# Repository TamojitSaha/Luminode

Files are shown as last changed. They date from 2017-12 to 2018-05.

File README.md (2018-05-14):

<h1 align="center"> LumiNode </h1> <br>

## Table of Contents
- [Introduction](#introduction)
- [Bill of Materials](#bill-of-materials)
- [Features](#features)
- [Contributors](#Contributors)
- [License](#license)
- [Acknowledgments](#acknowledgments)

## Introduction





A wireless multipurpose IoT (Internet of Things) compatible smart light system that can reproduce colour from any image in RGB colour space with intensity adjustment capability.
It is open-source and built for Arduino ecosystem making it suitable for hobbysist and beginners.
<p align="center">
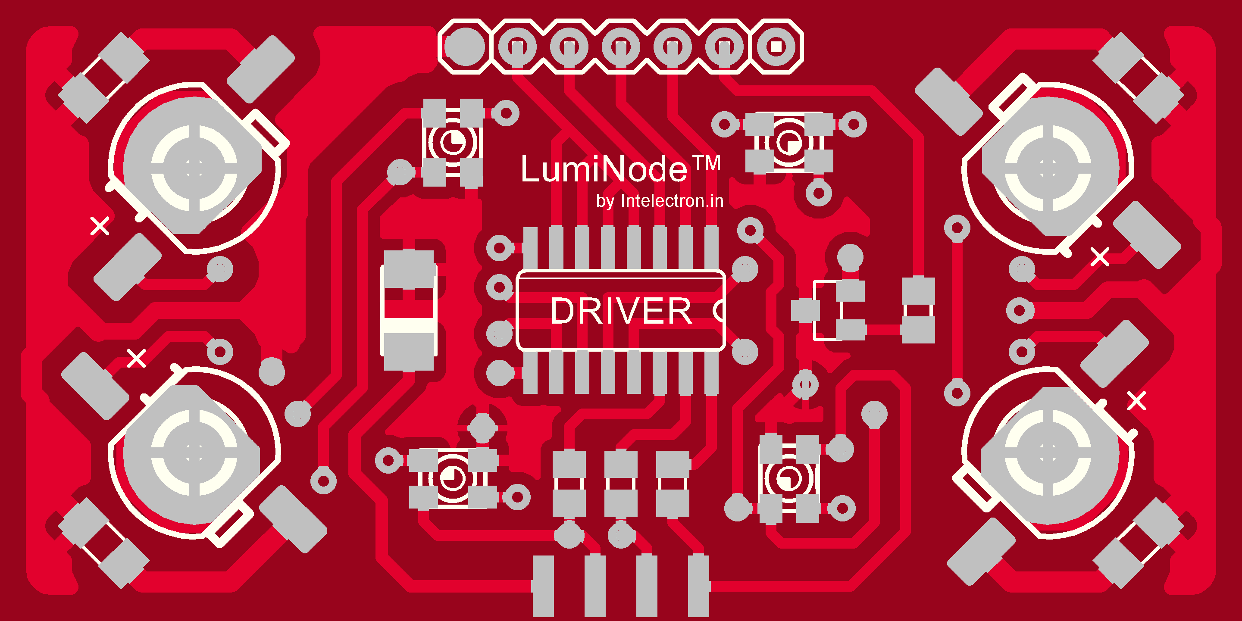
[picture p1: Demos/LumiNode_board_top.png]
  &nbsp 
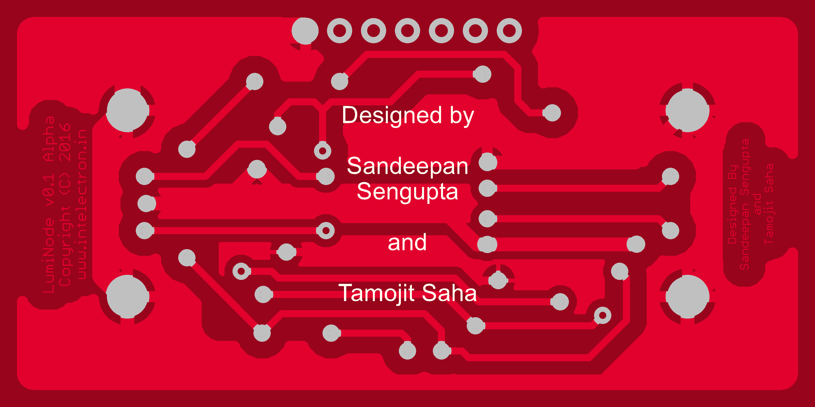
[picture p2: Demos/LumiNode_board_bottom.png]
  &nbsp 
</p>
<p align="center">
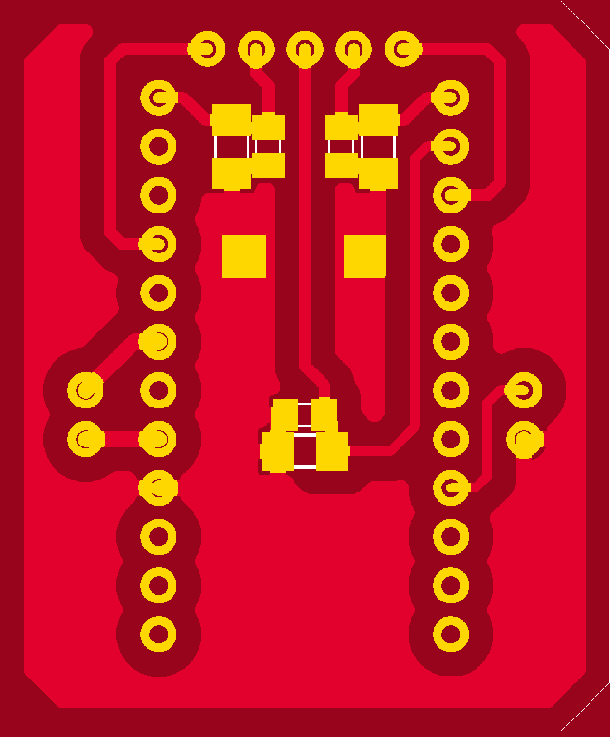
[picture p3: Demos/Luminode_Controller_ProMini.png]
  &nbsp
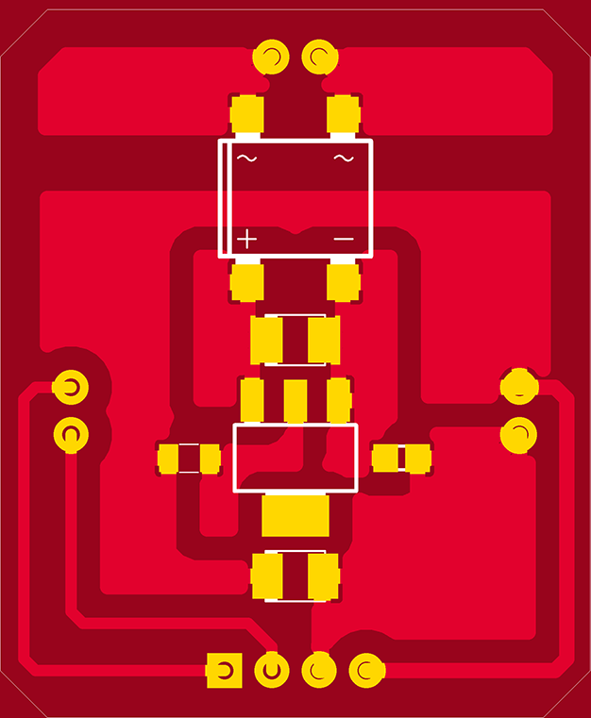
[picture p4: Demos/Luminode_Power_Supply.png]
  &nbsp
</p>
<p align="center">
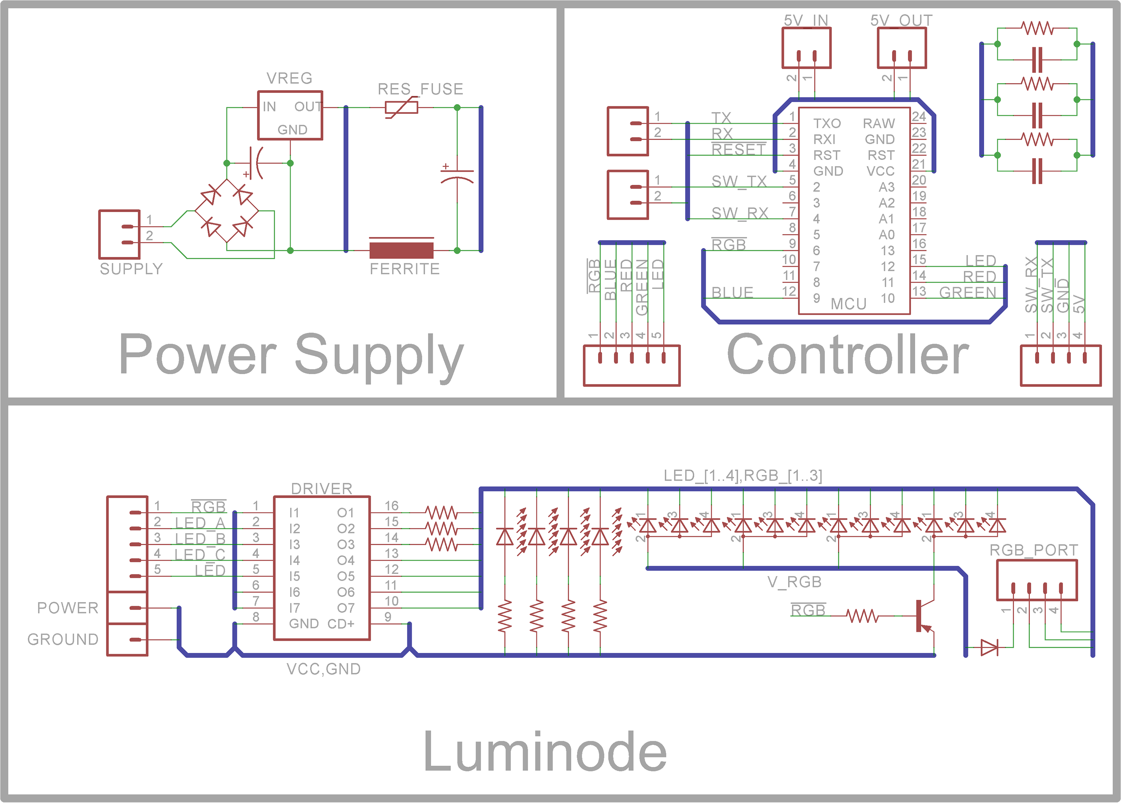
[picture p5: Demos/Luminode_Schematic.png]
  &nbsp
</p>

## Bill of Materials

        1. Arduino Pro Mini
        2. 7805 Voltage regulator
        3. Bluetooth module HC-05
        4. 4 x 3528 RGB LEDs
        5. 4 x 100 to 330ohm resistors in 0805 package
        6. 1 x ULN2003 smd
        7. 1 x MMBT2N2222
        8. 1 x 1Kohm in 0805 package
        9. 4 x 330ohm in 1206 package
        10. 1 x M7 diode(1N4007 smd version) 
        11. 1W cool white smd LED
        12. PCB fabrication materials.
        13. Single core wires for soldering PTH holes.
        14. DBS107G - Bridge Rectifier
        15. 2 x 10K in 1206 package
        16. 2 x 100nF in 0805 package
        17. 1 x ferrite chip 0805 package(optional: pads can be shorted in PCB)
        18. 1 x 1A PTC 0805 package(optional: pads can be shorted in PCB

## Features
- Simple UI
- Colour selection from any chosen image
- Real-time colour synchronization

## Contributors
Connect us here:
<br><br>
 <br>
 
<p> 
or <a href ="https://github.com/SandeepanSengupta/Luminode/issues/new/">file an issue</a>. Feature requests are always welcome.</p>

## License
Contents of this repository are realeased under [CC-BY-NC-SA 4.0](./LICENSE.md) <br>


## Acknowledgments
Thanks to the contributors! :wink:

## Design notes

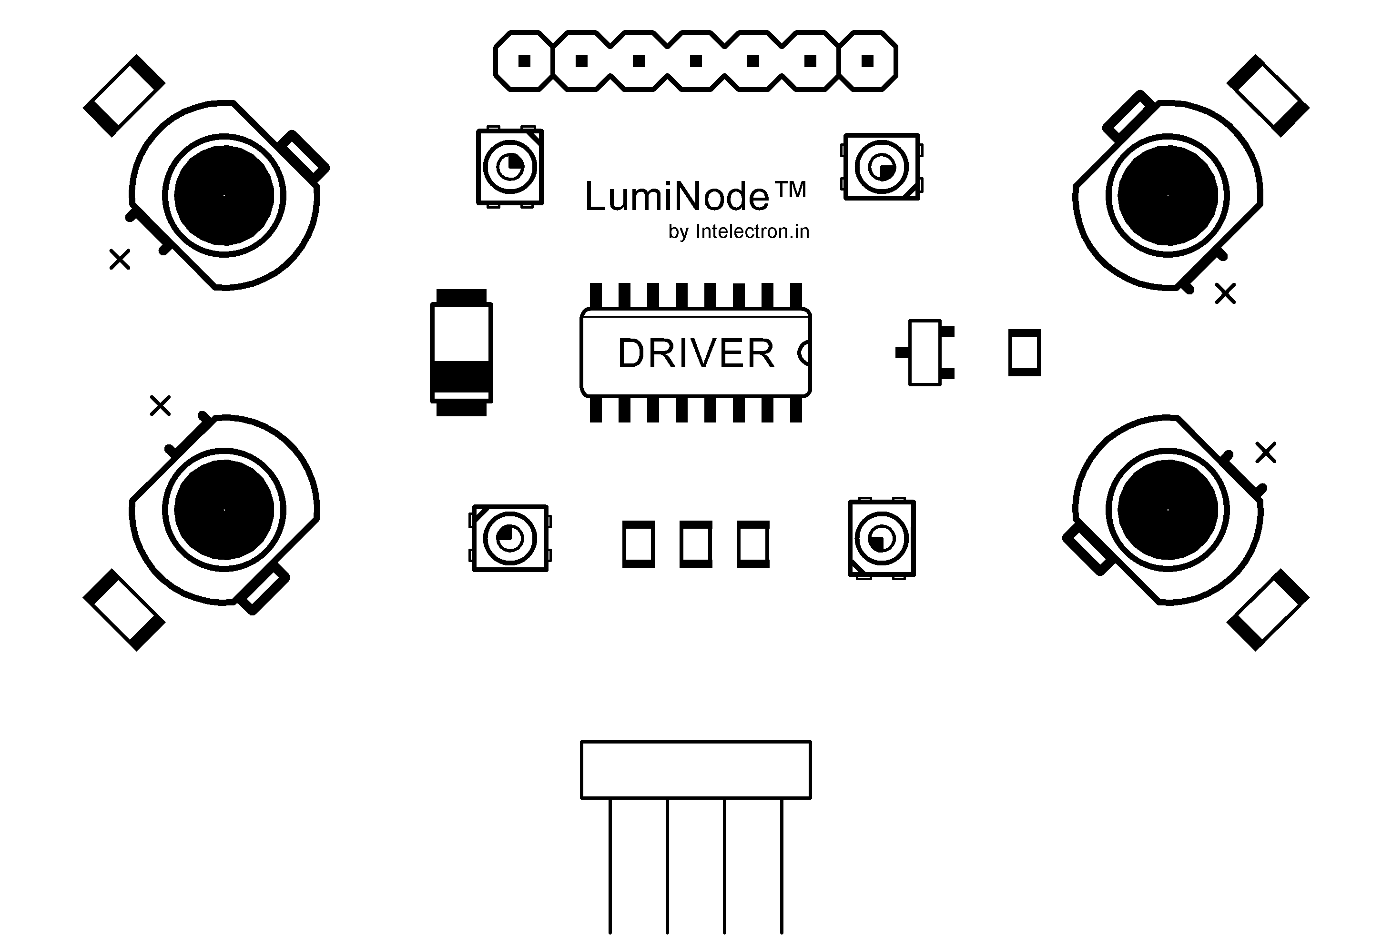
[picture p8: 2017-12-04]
Demos/LumiNode_top_silk.png

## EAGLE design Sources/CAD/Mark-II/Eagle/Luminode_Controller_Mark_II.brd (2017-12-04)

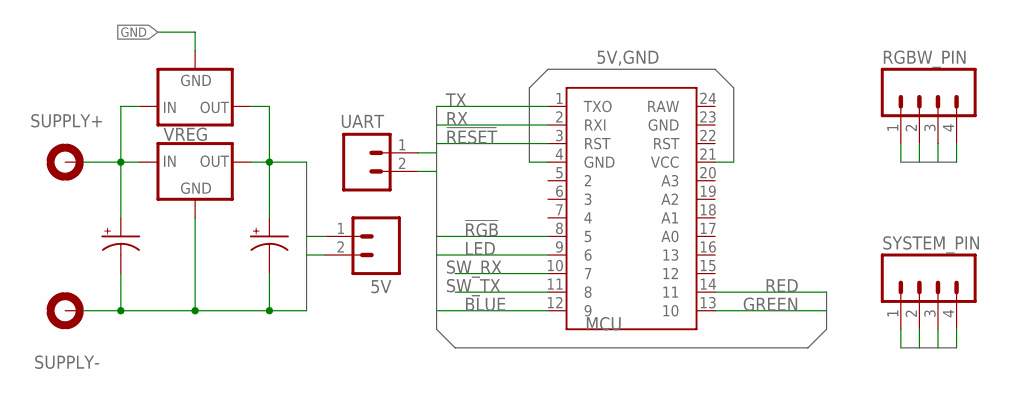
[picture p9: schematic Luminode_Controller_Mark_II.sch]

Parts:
5V: M02PTH; 1X02
C_IN: CPOL-USSMCB; SMC_B
C_OUT: CPOL-USSMCB; SMC_B
MCU: ARDUINO_MINI
RGBW_PIN: M04PTH; 1X04
SUPPLY+: +V; 3,0-PAD
SUPPLY-: -V; 3,0-PAD
SYSTEM_PIN: M04PTH; 1X04
UART: M02PTH; 1X02
VREG: 7805; SOT223
VREG_ALT: V_REG_78XXSINK; TO220-IGO

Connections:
5V: 5V.1, C_OUT.+, MCU.21 (VCC), SYSTEM_PIN.1, VREG.2 (OUT), VREG_ALT.OUT
!RESET: MCU.3 (RST)
!RGB: MCU.8 (5), SYSTEM_PIN.4
BLUE: MCU.12 (9), RGBW_PIN.3
GND: 5V.2, C_IN.-, C_OUT.-, MCU.4 (GND), SUPPLY-.B3,0, SYSTEM_PIN.3, VREG.1 (GND), VREG_ALT.GND
GREEN: MCU.13 (10), RGBW_PIN.2
LED: MCU.9 (6), RGBW_PIN.4
RED: MCU.14 (11), RGBW_PIN.1
RX: MCU.2 (RXI)
SW_RX: MCU.10 (7), UART.2
SW_TX: MCU.11 (8), UART.1
TX: MCU.1 (TXO)
VIN: C_IN.+, SUPPLY+.B3,0, SYSTEM_PIN.2, VREG.3 (IN), VREG_ALT.IN

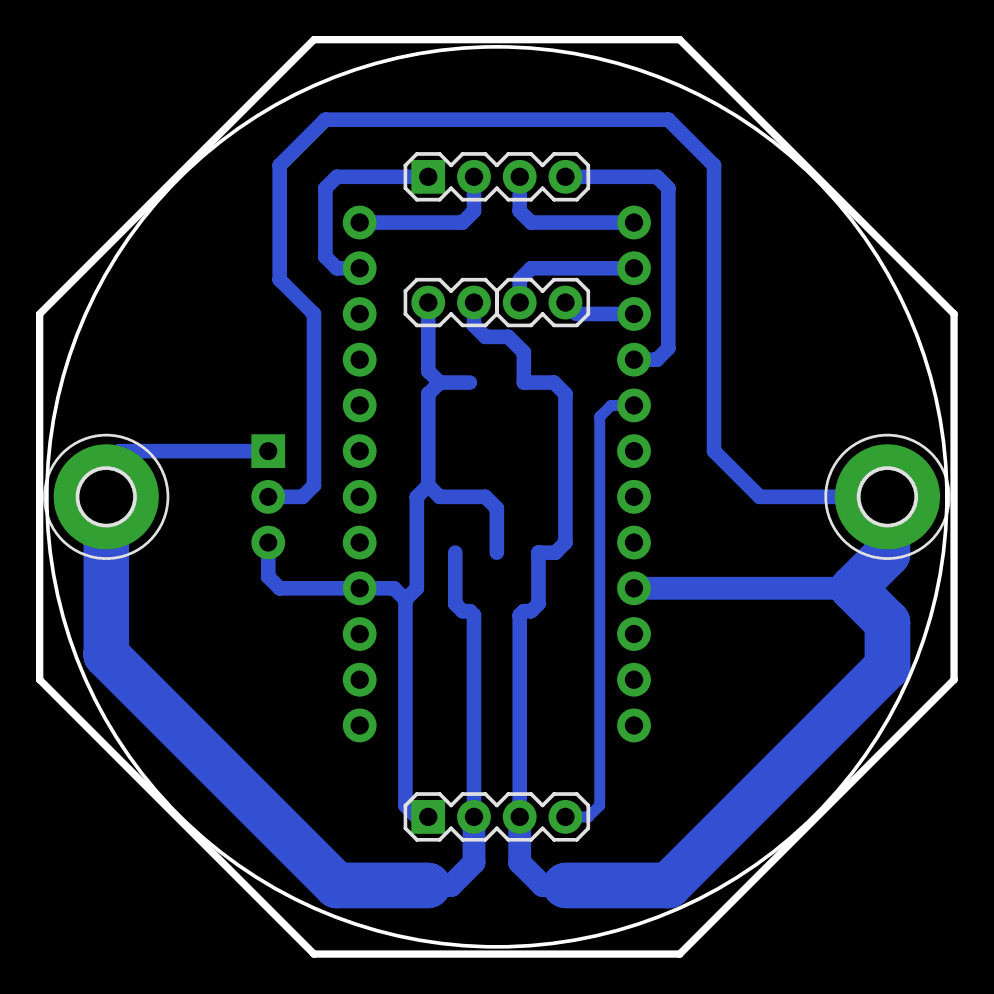
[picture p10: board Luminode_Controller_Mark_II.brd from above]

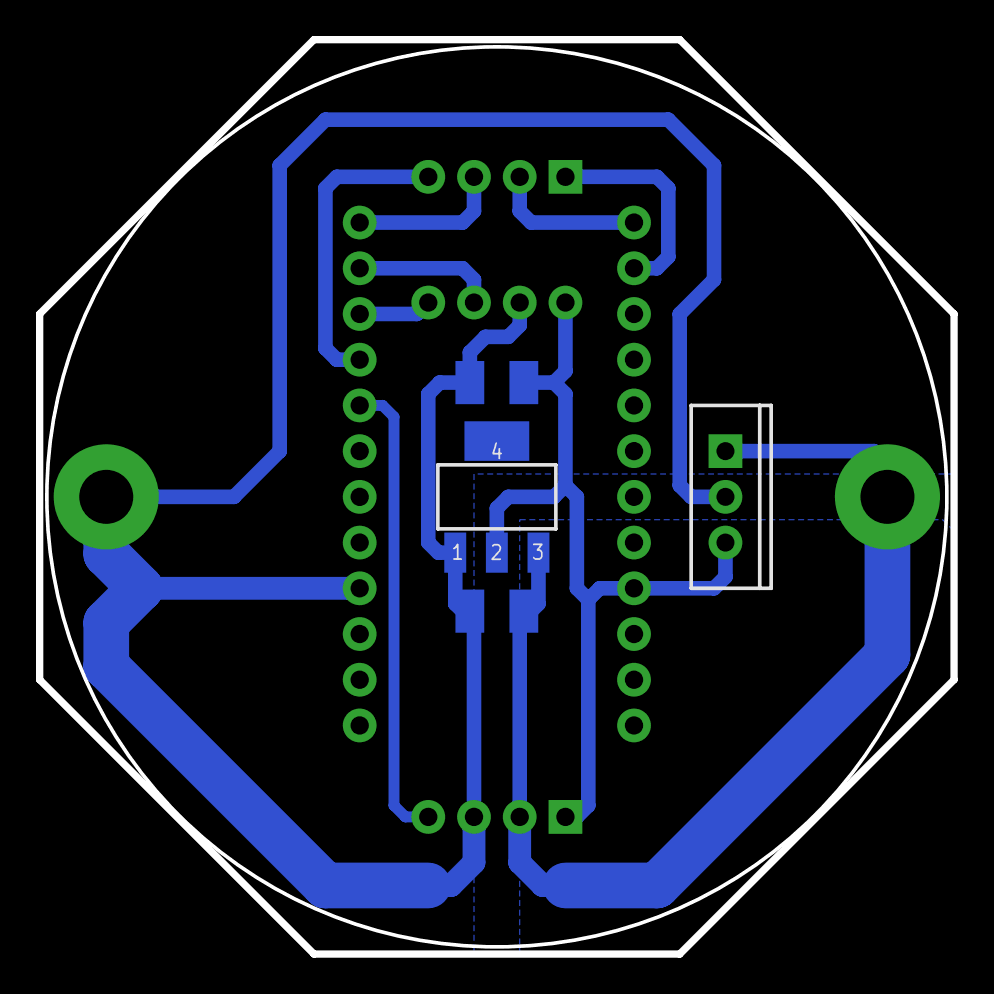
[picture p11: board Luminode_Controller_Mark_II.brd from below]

Board: 2 copper layers, 50.8 x 50.8 mm, 11 parts (4 on the bottom side), 10 nets.

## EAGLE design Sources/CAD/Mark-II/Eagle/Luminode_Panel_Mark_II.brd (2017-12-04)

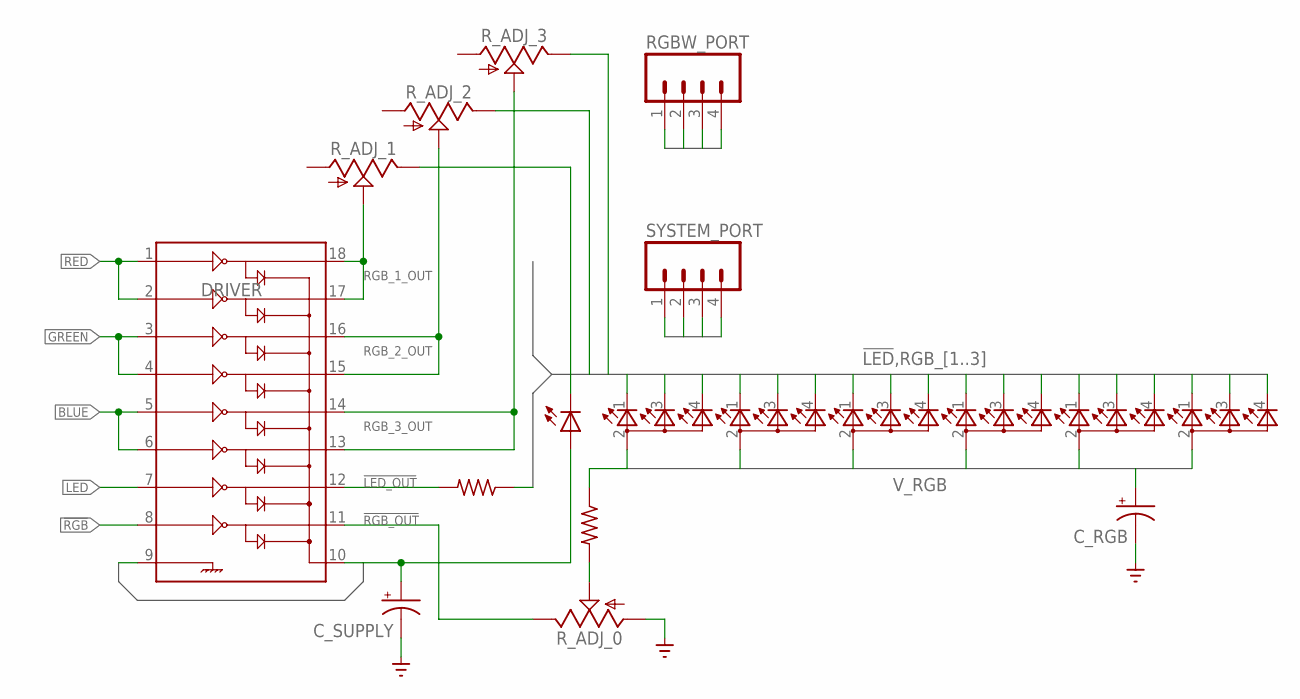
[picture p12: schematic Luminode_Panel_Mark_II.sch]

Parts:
C_RGB: CPOL-USE2.5-6; E2,5-6
C_SUPPLY: CPOL-USE2.5-6; E2,5-6
DRIVER: ULN2803SOICW; SO18L
LED: X42180; Z-POWER-LED-DOME-TYPE
LED_RGB_1, LED_RGB_2, LED_RGB_3, LED_RGB_4, LED_RGB_5, LED_RGB_6: TOPLED-3PLCC; P-LCC-4-3
RGBW_PORT: M04PTH; 1X04
R_ADJ_0, R_ADJ_1, R_ADJ_2, R_ADJ_3: 500E; B25P
R_LED: R-US_0309/10; 0309/10
R_RGB: R-US_0207/7; 0207/7
SYSTEM_PORT: M04PTH; 1X04

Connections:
5V: SYSTEM_PORT.1
!LED: LED.C, R_LED.1
!LED_OUT: DRIVER.12, R_LED.2
!RGB: DRIVER.8, SYSTEM_PORT.4
!RGB_OUT: DRIVER.11, R_ADJ_0.E
BLUE: DRIVER.5, DRIVER.6, RGBW_PORT.3
GND: C_RGB.-, C_SUPPLY.-, DRIVER.9, R_ADJ_0.A, SYSTEM_PORT.3
GREEN: DRIVER.3, DRIVER.4, RGBW_PORT.2
LED: DRIVER.7, RGBW_PORT.4
unnamed: R_ADJ_0.S, R_RGB.2
RED: DRIVER.1, DRIVER.2, RGBW_PORT.1
RGB_1: LED_RGB_1.1 (CRED), LED_RGB_2.1 (CRED), LED_RGB_3.1 (CRED), LED_RGB_4.1 (CRED), LED_RGB_5.1 (CRED), LED_RGB_6.1 (CRED), R_ADJ_1.E
RGB_1_OUT: DRIVER.17, DRIVER.18, R_ADJ_1.S
RGB_2: LED_RGB_1.3 (CBLUE), LED_RGB_2.3 (CBLUE), LED_RGB_3.3 (CBLUE), LED_RGB_4.3 (CBLUE), LED_RGB_5.3 (CBLUE), LED_RGB_6.3 (CBLUE), R_ADJ_2.E
RGB_2_OUT: DRIVER.15, DRIVER.16, R_ADJ_2.S
RGB_3: LED_RGB_1.4 (CGREEN), LED_RGB_2.4 (CGREEN), LED_RGB_3.4 (CGREEN), LED_RGB_4.4 (CGREEN), LED_RGB_5.4 (CGREEN), LED_RGB_6.4 (CGREEN), R_ADJ_3.E
RGB_3_OUT: DRIVER.13, DRIVER.14, R_ADJ_3.S
VIN: C_SUPPLY.+, DRIVER.10, LED.A, SYSTEM_PORT.2
V_RGB: C_RGB.+, LED_RGB_1.2 (A2), LED_RGB_2.2 (A2), LED_RGB_3.2 (A2), LED_RGB_4.2 (A2), LED_RGB_5.2 (A2), LED_RGB_6.2 (A2), R_RGB.1

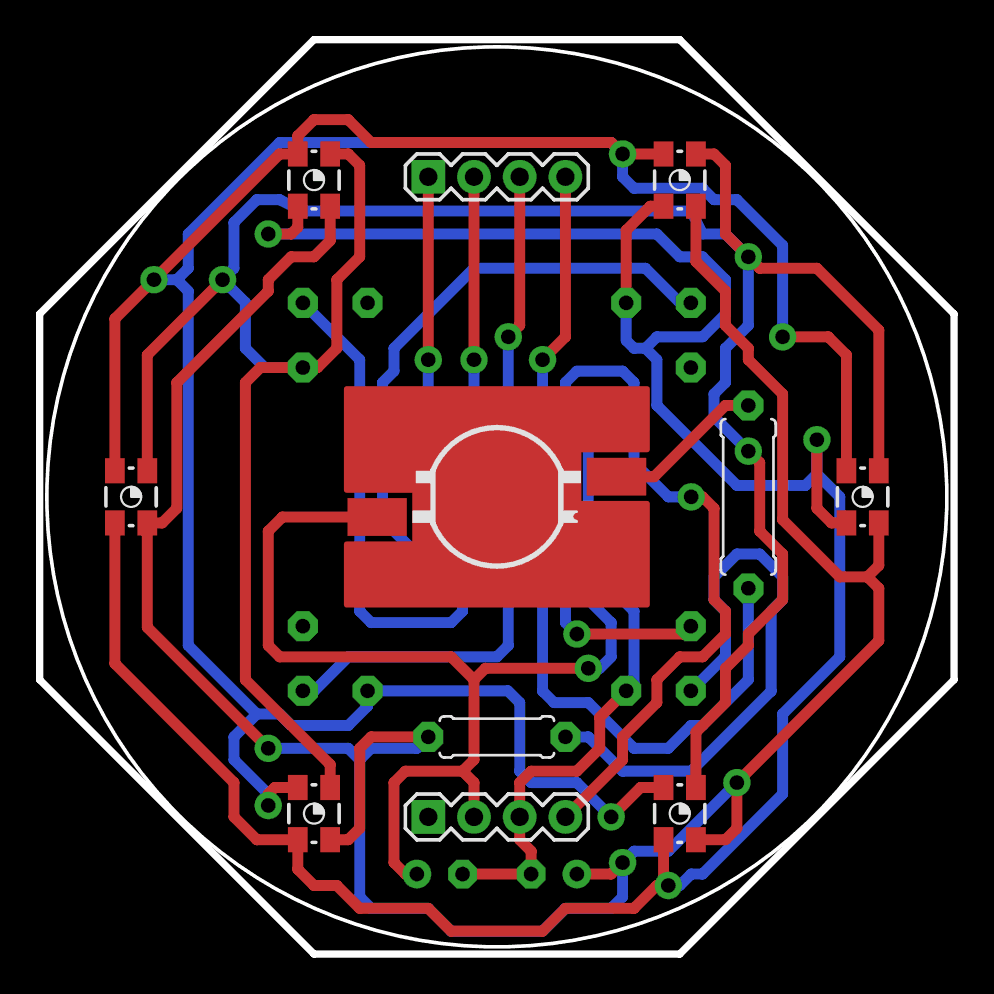
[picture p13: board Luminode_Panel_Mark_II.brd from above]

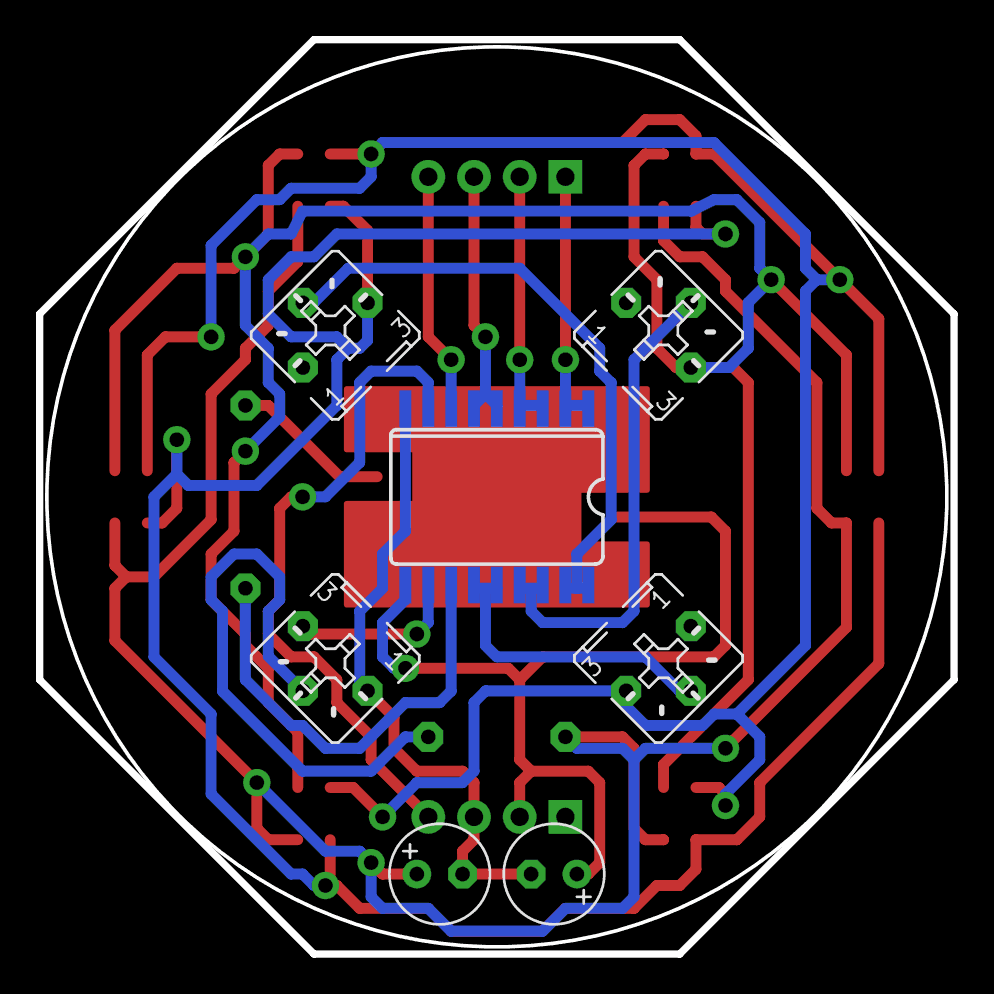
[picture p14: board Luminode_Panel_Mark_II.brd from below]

Board: 2 copper layers, 50.8 x 50.8 mm, 18 parts (7 on the bottom side), 18 nets.

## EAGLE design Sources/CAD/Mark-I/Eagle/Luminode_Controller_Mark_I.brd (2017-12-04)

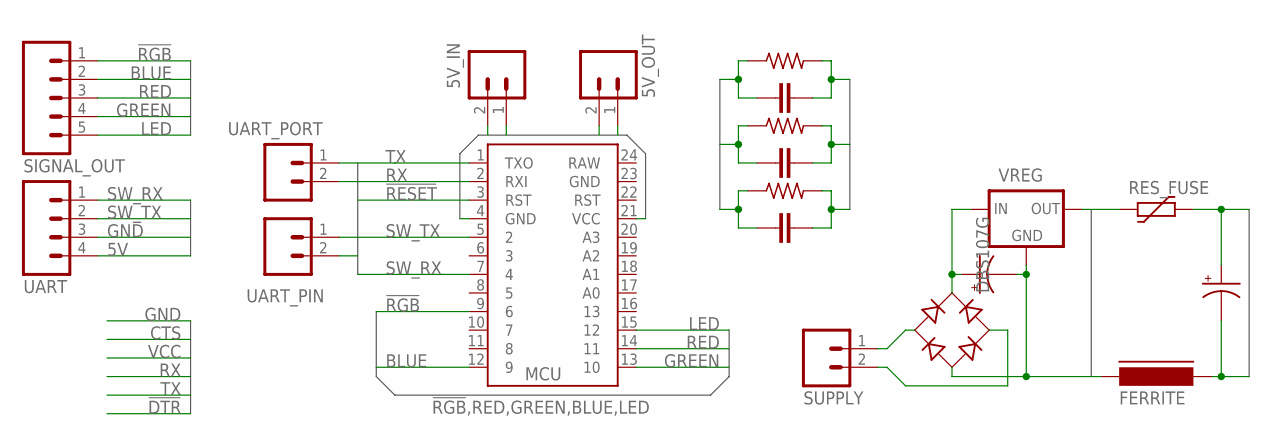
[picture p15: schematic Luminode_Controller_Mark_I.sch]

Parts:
5V_IN, 5V_OUT: M02PTH; 1X02
C_BLUE: C-EUC0805K; C0805K
C_GREEN: C-EUC0805K; C0805K
C_IN: CPOL-USSMCB; SMC_B
C_OUT: CPOL-USSMCB; SMC_B
C_RED: C-EUC0805K; C0805K
FERRITE: FERRITE-0805; FB805
MCU: ARDUINO_MINI
RECTIFIER: DBS107G; DBS
RES_FUSE: FUSE_PTC-0805; PTC0805
R_BLUE: R-US_M1206; M1206
R_GREEN: R-US_M1206; M1206
R_RED: R-US_M1206; M1206
SIGNAL_OUT: M05PTH; 1X05
SUPPLY: M02PTH; 1X02
UART: M04PTH; 1X04
UART_PIN: M02PTH; 1X02
UART_PORT: M02PTH; 1X02
VREG: 7805; SOT223

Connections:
5V: 5V_IN.1, 5V_OUT.1, C_OUT.+, MCU.21 (VCC), RES_FUSE.2, UART.4
!RESET: MCU.3 (RST)
!RGB: MCU.9 (6), SIGNAL_OUT.1
AC_EARTH: RECTIFIER.AC2, SUPPLY.2
AC_IN: RECTIFIER.AC1, SUPPLY.1
BLUE: C_BLUE.2, MCU.12 (9), R_BLUE.1, SIGNAL_OUT.2
EARTH: C_IN.-, FERRITE.2, RECTIFIER.-, VREG.1 (GND)
GND: 5V_IN.2, 5V_OUT.2, C_BLUE.1, C_GREEN.1, C_OUT.-, C_RED.1, FERRITE.1, MCU.4 (GND), R_BLUE.2, R_GREEN.2, R_RED.2, UART.3
GREEN: C_GREEN.2, MCU.13 (10), R_GREEN.1, SIGNAL_OUT.4
LED: MCU.15 (12), SIGNAL_OUT.5
RED: C_RED.2, MCU.14 (11), R_RED.1, SIGNAL_OUT.3
RX: MCU.2 (RXI)
SW_RX: MCU.7 (4), UART.1, UART_PIN.2, UART_PORT.2
SW_TX: MCU.5 (2), UART.2, UART_PIN.1, UART_PORT.1
TX: MCU.1 (TXO)
VIN: C_IN.+, RECTIFIER.+, VREG.3 (IN)
VOUT: RES_FUSE.1, VREG.2 (OUT)

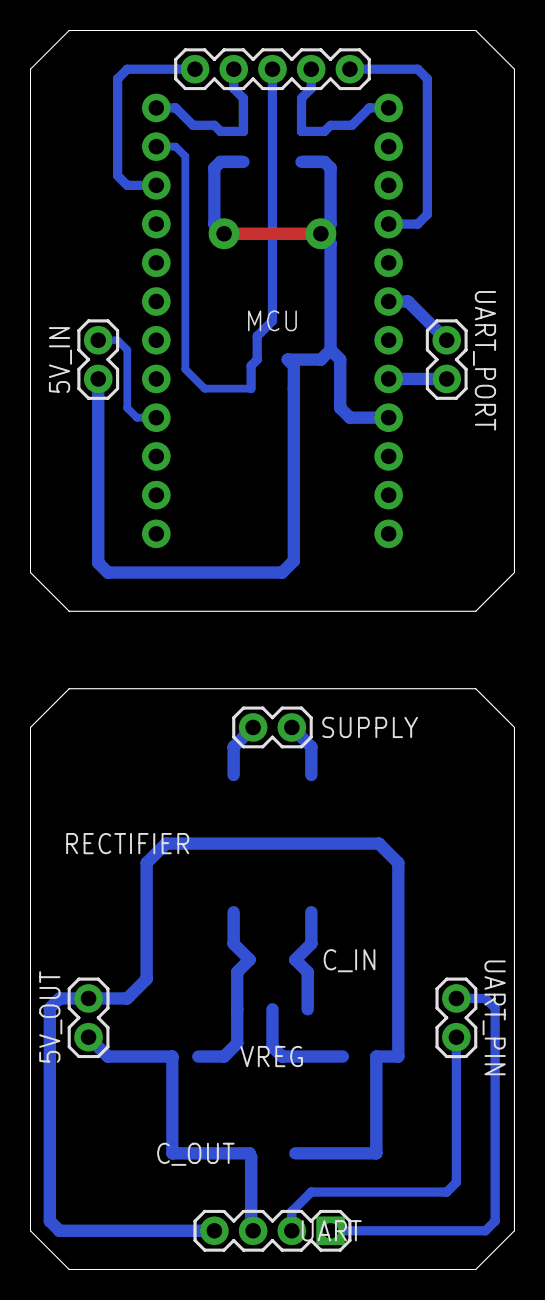
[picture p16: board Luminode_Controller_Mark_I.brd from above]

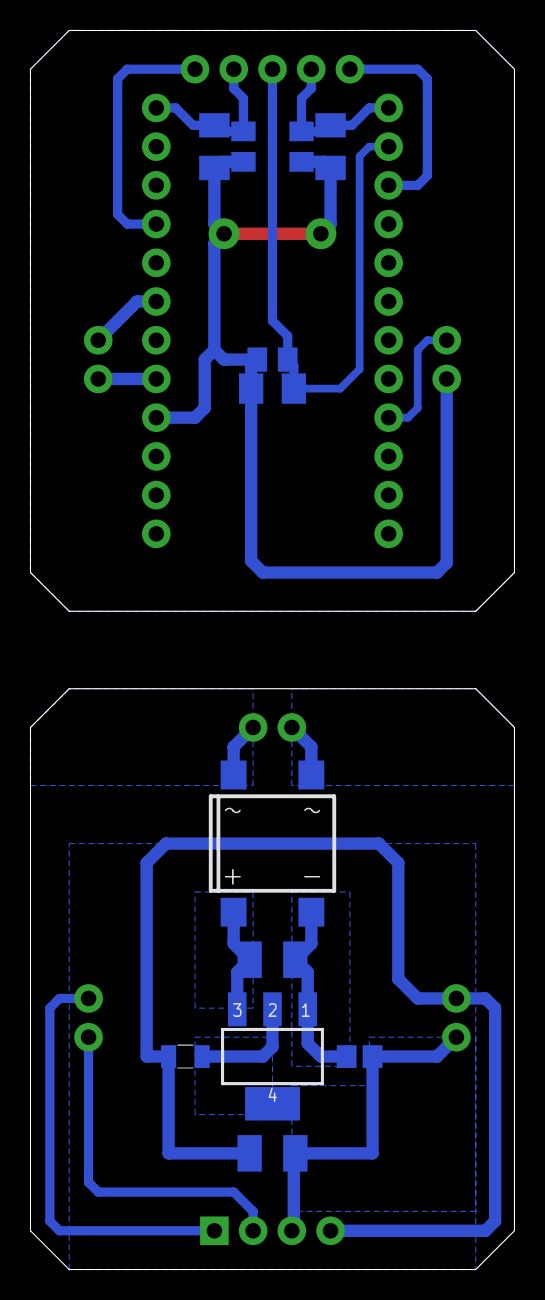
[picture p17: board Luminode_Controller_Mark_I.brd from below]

Board: 2 copper layers, 31.8 x 81.3 mm, 20 parts (12 on the bottom side), 14 nets.

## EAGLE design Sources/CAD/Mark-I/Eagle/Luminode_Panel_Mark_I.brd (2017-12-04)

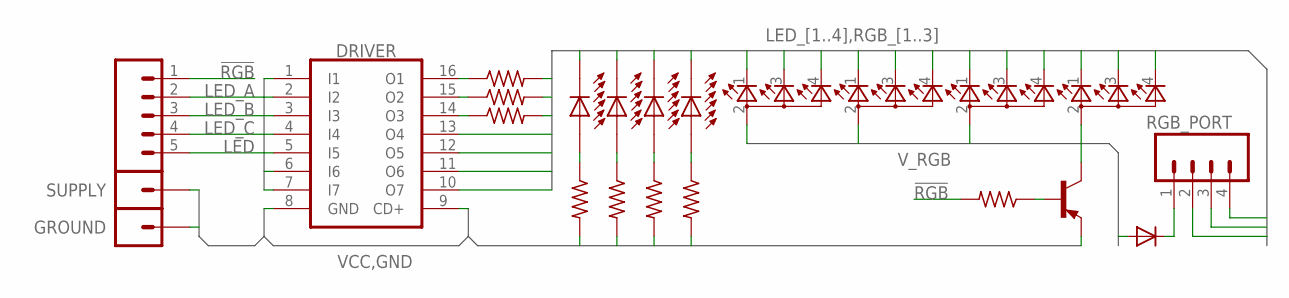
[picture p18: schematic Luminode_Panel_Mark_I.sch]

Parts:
DIODE: DIODE-DO-214AC; DO-214AC
DRIVER: ULN2003AD; SO16
GROUND: M01PTH; 1X01
LED_1, LED_2, LED_3, LED_4: LXHL-DB01; SIDE-EMITTING
LED_RGB_1, LED_RGB_2, LED_RGB_3, LED_RGB_4: TOPLED-3PLCC; P-LCC-4-3
RGB_PORT: M04SMD; 1X04-SMD
R_LED_1, R_LED_2, R_LED_3, R_LED_4: 100E; M1206
R_RGB: 100E; M0805
R_RGB_A: 100E; M0805
R_RGB_B: 100E; M0805
R_RGB_C: 100E; M0805
SIGNAL: M05PTH; 1X05
SUPPLY: M01PTH; 1X01
TRANSISTOR: BC807-16-PNP-SOT23-BEC; SOT23-BEC

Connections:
!RGB: R_RGB.2, SIGNAL.1
GND: DRIVER.8 (GND), GROUND.1
LED: DRIVER.4 (I4), DRIVER.5 (I5), DRIVER.6 (I6), DRIVER.7 (I7), SIGNAL.5
LED_1: DRIVER.13 (O4), LED_1.CATHODE (C)
LED_2: DRIVER.10 (O7), LED_2.CATHODE (C)
LED_3: DRIVER.11 (O6), LED_3.CATHODE (C)
LED_4: DRIVER.12 (O5), LED_4.CATHODE (C)
LED_A: DRIVER.1 (I1), SIGNAL.2
LED_B: DRIVER.2 (I2), SIGNAL.3
LED_C: DRIVER.3 (I3), SIGNAL.4
unnamed: DRIVER.16 (O1), R_RGB_A.1
unnamed: DRIVER.15 (O2), R_RGB_B.1
unnamed: DRIVER.14 (O3), R_RGB_C.1
unnamed: LED_1.ANODE (A), R_LED_1.1
unnamed: LED_2.ANODE (A), R_LED_2.1
unnamed: LED_3.ANODE (A), R_LED_3.1
unnamed: LED_4.ANODE (A), R_LED_4.1
unnamed: R_RGB.1, TRANSISTOR.B
RGB_1: LED_RGB_1.1 (CRED), LED_RGB_2.1 (CRED), LED_RGB_3.1 (CRED), LED_RGB_4.1 (CRED), RGB_PORT.4, R_RGB_A.2
RGB_2: LED_RGB_1.3 (CBLUE), LED_RGB_2.3 (CBLUE), LED_RGB_3.3 (CBLUE), LED_RGB_4.3 (CBLUE), RGB_PORT.3, R_RGB_B.2
RGB_3: LED_RGB_1.4 (CGREEN), LED_RGB_2.4 (CGREEN), LED_RGB_3.4 (CGREEN), LED_RGB_4.4 (CGREEN), RGB_PORT.2, R_RGB_C.2
RGB_EXT: DIODE.C, RGB_PORT.1
VCC: DRIVER.9 (CD+), R_LED_1.2, R_LED_2.2, R_LED_3.2, R_LED_4.2, SUPPLY.1, TRANSISTOR.E
V_RGB: DIODE.A, LED_RGB_1.2 (A2), LED_RGB_2.2 (A2), LED_RGB_3.2 (A2), LED_RGB_4.2 (A2), TRANSISTOR.C

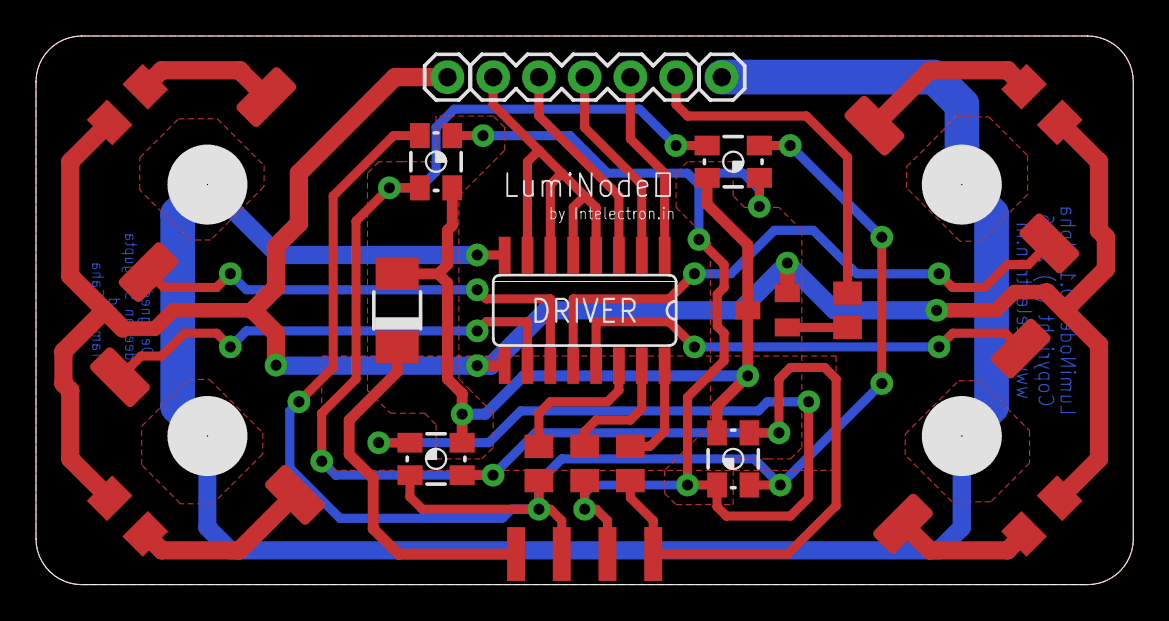
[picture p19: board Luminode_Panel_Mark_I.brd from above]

Board: 2 copper layers, 61.0 x 30.5 mm, 23 parts (0 on the bottom side), 24 nets.

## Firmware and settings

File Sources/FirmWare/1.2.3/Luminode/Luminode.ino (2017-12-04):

/*
  Communication framework for Luminode v1.2.3
  Author(s): Sandeepan Sengupta, Tamojit Saha
  Special thanks to: Sumant Banerjee, B.Tech (Electrical Engineering), West Bengal University of Technology


  Frame format:

  Inputs are 8 charecters in an UART stream
  Charector 1 is Identifier
  Charector 2~7 are Payload in HEX charectors
  Charector 8 is Termination indicator

  Registered identifier(s): '~', '@' and '#'
  Registered termination indicator(s): ';'

  '~' is identified as configuration data
  '@' is identified as Neopixel RGB address
  '#' is identified as RGB data

  RGB payload (both address and data) is 6 charectors HEX in 2+2+2 = 6 format (#000000; to #ffffff;)

  Configuration payload is converted into 24 charectors BIN from 6 charector HEX
  24 charectors BIN in in 1+8+(5+5+5) = 24 format
  1st bit (BIT_0) used to change LED State
  2nd to 9th bit (BIT_1 ~ BIT_8) is used to produce PWM code for intensity adjustment
  Rest of the bit(all 15 of them in 5+5+5 format) are used to feed shift registers secondary configuration data to drive 5x5x5 LED cube

  Accepted input formats are
  (Single frame)
  ~000000;
  @000000;
  #000000;
  etc...

  (Multiple frames without seperation)
  ~000000;@000000;#000000;
  ~A0b1C2;@f0E1d2;#9F8e7D;
  etc...

  Test Code : ~a0b1c2;#0a1B2c;@6C5b4A;#f9e8d7;


  Copyright (c) 2015-2016, Intelectron India (https://www.intelectron.in)
*/

#define id_length 1
#define code_length 6

#define PWM_res 8
#define BIT_width 5

#define _debug_

uint8_t RGB_pin[3] = {9, 10, 11};

bool Register[16] = {};
uint8_t payload[2], address[3], RGB_value[3], segment[5] = {};

void setup()
{
  Serial.begin(9600);
  while (!Serial)
  {
    ;
  }
  for (uint8_t j = 0; j < 3; j++)
  {
    pinMode(RGB_pin[j], OUTPUT);
  }
}

void loop()
{
  Serial.flush();
  while (Serial.available() != NULL)
  {
    char tmp[id_length + code_length] = {};
    const uint8_t _tmp = sizeof(tmp) / sizeof(char);

    Serial.readBytesUntil(';', tmp, _tmp);
    if (strlen(tmp) >= _tmp)
    {
      char id = NULL;
      boolean change = false;
      uint32_t code = NULL;
      bool bin[code_length * 4] = {}; //bool bin[strlen(tmp)] = {}; //strlen(tmp) consumes less space and works but I've no idea how or why.

      id = tmp[0];
      uint8_t i, j = NULL;
      String code_string = "";

      const uint8_t _segment = sizeof(segment) / sizeof(uint8_t);
      const uint8_t _payload = sizeof(payload) / sizeof(uint8_t);
      const uint8_t _Register = sizeof(Register) / sizeof(bool);

      for (i = id_length; i < _tmp; i++)
      {
        code_string = String(code_string + String(tmp[i]));
      }
      code = (uint32_t) strtol( &code_string[0], NULL, HEX);
#ifdef _debug_
      Serial.print("Entered string data is\t\t:\t'");
      Serial.print(id);
      Serial.print(code_string);
      Serial.println("'");

      Serial.print("Rectified code (in HEX) is\t:\t");
      Serial.print(code, HEX);
      Serial.println("\n");

      Serial.print("Configuration code in DEC\t:\t");
      Serial.println(code, DEC);
      Serial.print("Configuration code in BIN\t:\t");
      Serial.println(code, BIN);
#endif

      switch (id)
      {
        case '~':
          for (i = 0; i < _segment; i++)
          {
            segment[i] = NULL;
          }

          while (code > 0)
          {
            bin[j] = code % 2;
#ifdef _debug_
            Serial.print("Bit number ");
            Serial.print(j + 1);
            Serial.print(" or BIT_");
            Serial.print(j);
            Serial.print(" is\t:\t");
            Serial.println(bin[j]);
#endif
            j++;
            code = code / 2;
          }

          segment[0] = bin[0];
          for (i = 0; i < PWM_res; i++)
          {
            segment[1] += round(bin[i + id_length] * pow(2, i));
          }
          for (j = 0 ; j < 3; j++)
          {
            for (i = 0; i < BIT_width; i++)
            {
              segment[2 + j] += round(bin[i + 1 + PWM_res + BIT_width * j] * pow(2, i));
            }
          }
          for (i = 0; i < BIT_width * 3; i++)
          {
            Register[i + 1] = bin[i + 1 + PWM_res];
          }
          for (j = 0; j < _payload; j++)
          {
            payload[j] = NULL;
            for (i = 0; i < _Register / 2; i++)
            {
              payload[j] += round(Register[i + (_Register / 2) * j] * pow(2, i));
            }
          }
#ifdef _debug_
          Serial.print("\nConfiguration frame (in BIN) is\t:\t[");
          Serial.print(segment[0], BIN);
          Serial.print(",");
          Serial.print(segment[1], BIN);
          Serial.print(",(");
          Serial.print(segment[2], BIN);
          Serial.print(",");
          Serial.print(segment[3], BIN);
          Serial.print(",");
          Serial.print(segment[4], BIN);
          Serial.println(")]");
          Serial.print("Configuration frame (in HEX) is\t:\t[");
          Serial.print(segment[0], HEX);
          Serial.print(",");
          Serial.print(segment[1], HEX);
          Serial.print(",(");
          Serial.print(segment[2], HEX);
          Serial.print(",");
          Serial.print(segment[3], HEX);
          Serial.print(",");
          Serial.print(segment[4], HEX);
          Serial.println(")]");
          Serial.print("System state is\t\t\t:\t");
          Serial.println(segment[0]);
          Serial.print("Configuration value is\t\t:\t");
          Serial.println(segment[1], HEX);
          Serial.print("5x5x5 LED cube configuration is\t:\t(");
          Serial.print(segment[2]);
          Serial.print(",");
          Serial.print(segment[3]);
          Serial.print(",");
          Serial.print(segment[4]);
          Serial.println(")");
          Serial.print("RGB state is\t\t\t:\t");
          Serial.println(Register[0]);
          Serial.print("First shift register code is\t:\t");
          Serial.println(payload[0], HEX);
          Serial.print("Second shift register code is\t:\t");
          Serial.println(payload[1], HEX);
          Serial.println("\n");
#endif
          break;

        case '@':
          address[0] = code >> 16;
          address[1] = code >> 8 & 0xFF;
          address[2] = code & 0xFF;
#ifdef _debug_
          Serial.print("Address of X axis\t\t:\t");
          Serial.println(address[0]);
          Serial.print("Address of Y axis\t\t:\t");
          Serial.println(address[1]);
          Serial.print("Address of Z axis\t\t:\t");
          Serial.println(address[2]);
          Serial.print("Neopixel address code set is\t:\t(");
          Serial.print(address[0], HEX);
          Serial.print(",");
          Serial.print(address[1], HEX);
          Serial.print(",");
          Serial.print(address[2], HEX);
          Serial.println(")");
          Serial.print("RGB color value set is\t\t:\t(");
          Serial.print(RGB_value[0], HEX);
          Serial.print(",");
          Serial.print(RGB_value[1], HEX);
          Serial.print(",");
          Serial.print(RGB_value[2], HEX);
          Serial.println(")");
          Serial.println("\n");
#endif
          break;

        case '#':
          RGB_value[0] = code >> 16;
          RGB_value[1] = code >> 8 & 0xFF;
          RGB_value[2] = code & 0xFF;

          if (RGB_value[0] != NULL || RGB_value[1] != NULL || RGB_value[2] != NULL)
          {
            Register[0] = HIGH;
          }
          else
          {
            Register[0] = LOW;
          }
          for (j = 0; j < _payload; j++)
          {
            payload[j] = NULL;
            for (i = 0; i < _Register / 2; i++)
            {
              payload[j] += round(Register[i + (_Register / 2) * j] * pow(2, i));
            }
          }
#ifdef _debug_
          Serial.print("RED is\t\t\t\t:\t");
          Serial.println(RGB_value[0]);
          Serial.print("GREEN is\t\t\t:\t");
          Serial.println(RGB_value[1]);
          Serial.print("BLUE is\t\t\t\t:\t");
          Serial.println(RGB_value[2]);
          Serial.print("Neopixel address code set is\t:\t(");
          Serial.print(address[0], HEX);
          Serial.print(",");
          Serial.print(address[1], HEX);
          Serial.print(",");
          Serial.print(address[2], HEX);
          Serial.println(")");
          Serial.print("RGB color value set is\t\t:\t(");
          Serial.print(RGB_value[0], HEX);
          Serial.print(",");
          Serial.print(RGB_value[1], HEX);
          Serial.print(",");
          Serial.print(RGB_value[2], HEX);
          Serial.println(")");
          Serial.print("RGB state is\t\t\t:\t");
          Serial.println(Register[0]);
          Serial.print("First shift register code is\t:\t");
          Serial.println(payload[0], HEX);
          Serial.print("Second shift register code is\t:\t");
          Serial.println(payload[1], HEX);
          Serial.println("\n");
#endif
          for (j = 0; j < 3; j++)
          {
            analogWrite(RGB_pin[j], RGB_value[j]);
          }
          break;

        default:
          exit(NULL);
          break;
      }
    }
  }
}

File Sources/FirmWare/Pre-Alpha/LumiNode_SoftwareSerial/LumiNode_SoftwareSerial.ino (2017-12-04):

/*
Luminode 
Developed by Tamojit Saha and Sandeepan Sengupta
Baccalaureus Technologie, Electronics and Communication Enginering, Techno India University

Firmware v1.0
Sumant Banerjee
Baccalaureus Technologie, Electrical Engineering, West Bengal University of Technology

Copyright (c) 2015-2016
*/

#include <SoftwareSerial.h>

#define WHITE   1
#define SLIDER  2
#define RGB     3
#define COLOR   4

int redPin=10;
int greenPin=11;
int bluePin=12;

int whitePin=13;
int RGB_EN_Pin=5;
int RGBstate=0;
int WHITEstate=0;

SoftwareSerial BT(14,15);

//comment the following line to disable debugging mode
#define __DEBUG_
String codes[] = {"", "WHITE", "SLIDER", "RGB", "COLOR"};
void setup()
{
  Serial.begin(9600);
  BT.begin(9600);
#ifdef __DEBUG_
  Serial.println("DEBUG mode ON");
#endif
  pinMode(redPin,OUTPUT);
  pinMode(greenPin,OUTPUT);
  pinMode(bluePin,OUTPUT);
  pinMode(whitePin,OUTPUT);
  pinMode(RGB_EN_Pin,OUTPUT);
}

void loop()
{
  if(BT.available())
  {
    processSerial();
  }
}
void processSerial()
{
  char _temp[20] = {};
  int code = -1;
  BT.readBytesUntil('#', _temp, 20);
  String buffer = String(buffer);
  Serial.println(_temp);
  //check which code was sent
  switch (buffer[0])
  {
    case '$':
      code = WHITE;
      break;
    case '@':
      code = RGB;
      break;
    case '!':
      code = SLIDER;
      break;
    case '%':
      code = COLOR;
      break;
  }
  buffer.remove(0, 1); //removes the identifier
  processSerialData(buffer, code);
  #ifdef __DEBUG_
  Serial.println(codes[code]);
  #endif
  Serial.flush();
}
void processSerialData(String buffer, int code)
{
  switch (code)
  {
    case WHITE:
      processWhite(buffer);
      break;
    case RGB:
      processRGB(buffer);
      break;
    case SLIDER:
      processSlider(buffer);
      break;
    case COLOR:
      processColor(buffer);
      break;
  }
}
void processWhite(String buffer)
{
  char state = buffer[0];
  if (state == '1')
  {
    buffer.remove(0, 2);
    WHITEstate=1;
    //TURN ON WHITE LED
    int brightness = buffer.toInt();
    #ifdef __DEBUG_
    Serial.println("White LED turned ON");
    Serial.print("brightness");
    Serial.println(brightness);
    #endif
    analogWrite(whitePin,brightness);
  }
  else if (state == '0')
  {
    //turn off white led
    WHITEstate=0;
    analogWrite(whitePin,0);
    #ifdef __DEBUG_
    Serial.println("White LED turned OFF");
    #endif
  }
}
void processRGB(String buffer)
{
  char state = buffer[0];
  if (state == '1')
  {
    //turn on rgb
    RGBstate=1;
    digitalWrite(RGB_EN_Pin,LOW);       //Turn !ON RGB Led
    #ifdef __DEBUG_
    Serial.println("RGB turned ON");
    #endif
  }
  else if (state == '0')
  {
    //turn off rgb
    RGBstate=0;
    digitalWrite(RGB_EN_Pin,HIGH);      //Turn !OFF RGB Led
    #ifdef __DEBUG_
    Serial.println("RGB turned OFF");
    #endif
  }
}
void processSlider(String buffer)
{
  int brightness = buffer.toInt();
  #ifdef __DEBUG_
  Serial.print("Brightness set to ");
  Serial.println(brightness);
  if(WHITEstate==1)
  analogWrite(whitePin,brightness); //write brightness value to white LED
  #endif
}
void processColor(String buffer)
{
  //process your RGB string 255,255,255
  #ifdef __DEBUG_
  Serial.println(buffer);
  #endif
  String red="",green="",blue="";
  
  int i1=buffer.indexOf(',');
  int i2=buffer.indexOf(',',i1+1);

  for(int i=0;i<i1;i++)
  {
    red+=buffer[i];
  }
  for(int i=i1+1;i<i2;i++)
  {
    green+=buffer[i];
  }
  buffer.remove(0,i2+1);
  int r=red.toInt();
  int g=green.toInt();
  int b=buffer.toInt();
  #ifdef __DEBUG_
  Serial.print("Red: ");
  Serial.println(r);
  Serial.print("Green: ");
  Serial.println(g);
  Serial.print("Blue: ");
  Serial.println(b);
  #endif
  if(RGBstate==1)
  {
    setRGB(r,g,b);  
  }
}
void setRGB(int _r, int _g, int _b)
{
  analogWrite(redPin,_r);
  analogWrite(greenPin,_g);
  analogWrite(bluePin,_b);
  #ifdef __DEBUG_
  Serial.print("Set Color");
  #endif
}

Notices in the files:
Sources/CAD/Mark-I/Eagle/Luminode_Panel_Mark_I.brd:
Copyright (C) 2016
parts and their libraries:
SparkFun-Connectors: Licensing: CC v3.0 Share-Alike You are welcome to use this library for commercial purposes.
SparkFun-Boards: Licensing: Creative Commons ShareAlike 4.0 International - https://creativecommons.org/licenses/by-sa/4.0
